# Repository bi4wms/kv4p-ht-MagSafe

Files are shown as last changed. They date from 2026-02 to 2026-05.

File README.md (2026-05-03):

# kv4p-ht-MagSafe
MagSafe version for kv4p-ht. Work in progress.

<a href="https://www.buymeacoffee.com/bi4wms" target="_blank">Buy Me a Coffee</a>
---

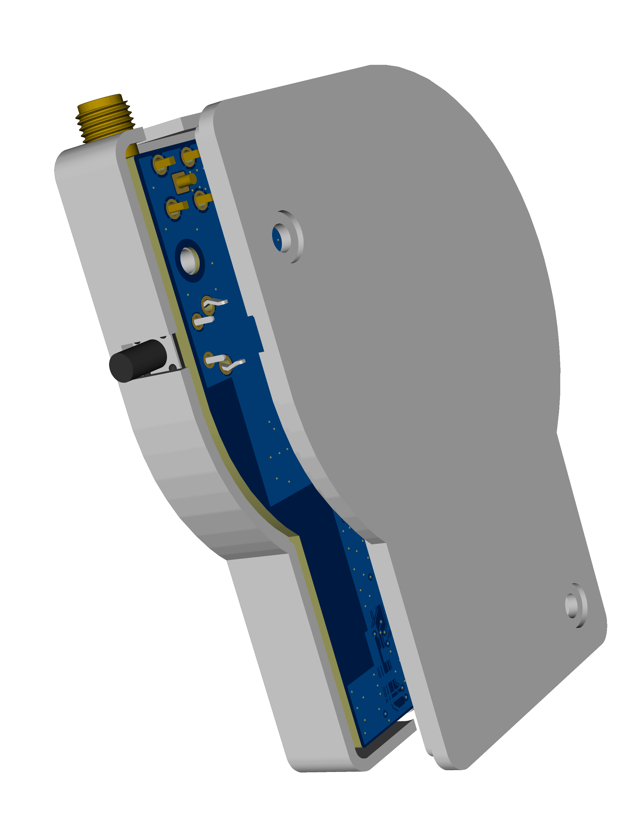
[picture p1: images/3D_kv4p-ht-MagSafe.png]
 

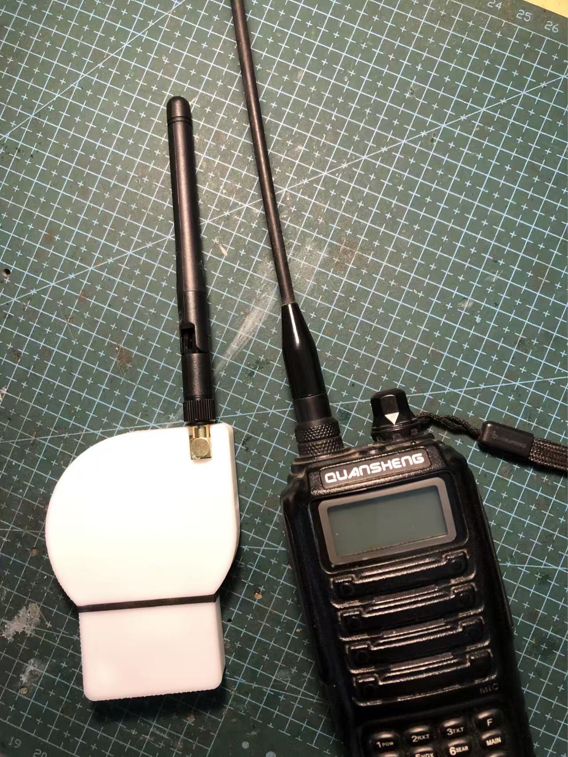
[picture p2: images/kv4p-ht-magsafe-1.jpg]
 

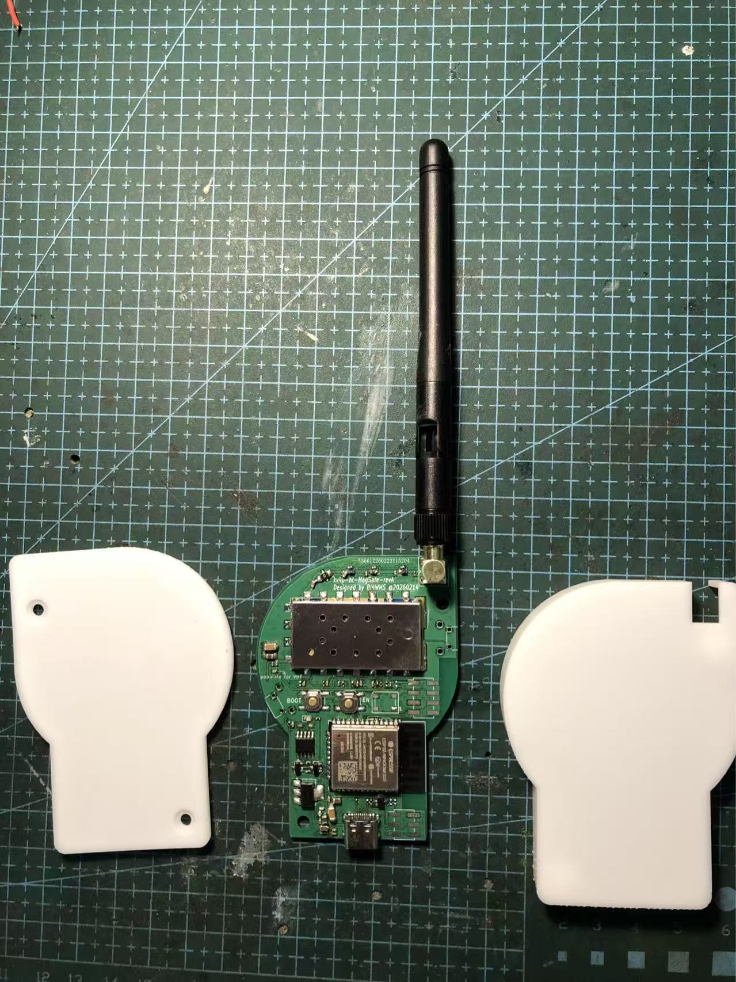
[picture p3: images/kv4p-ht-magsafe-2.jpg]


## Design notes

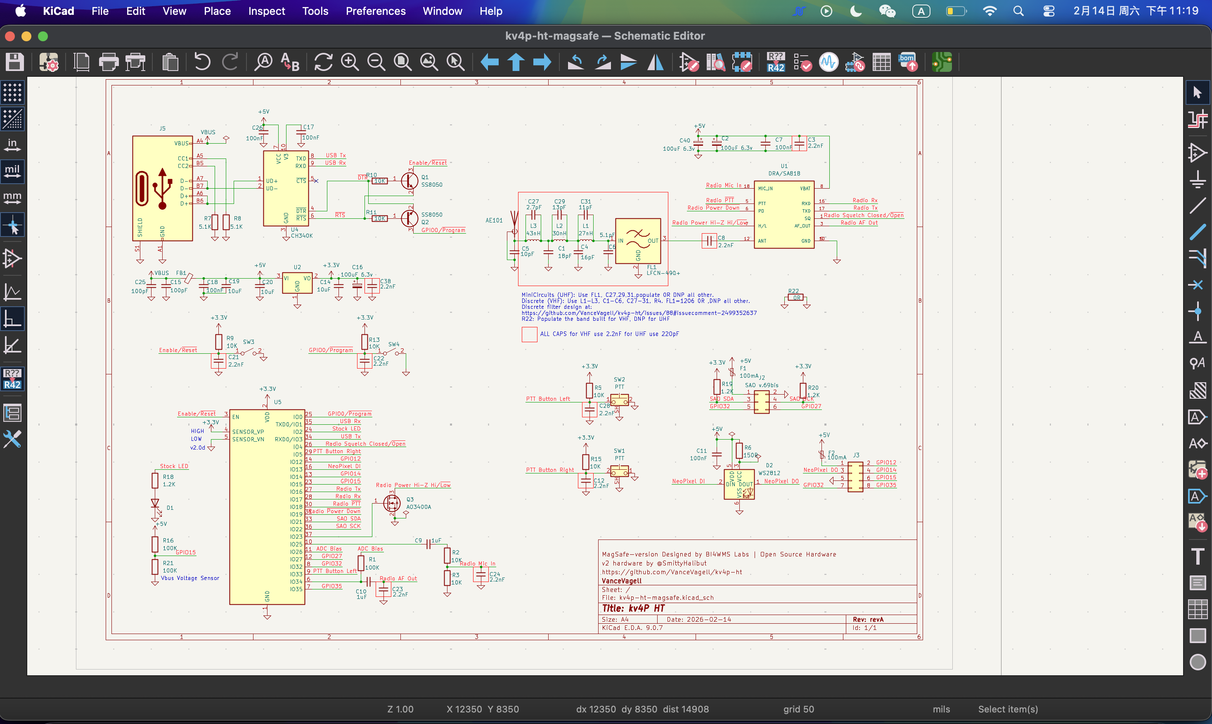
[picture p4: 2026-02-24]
images/schematics.png

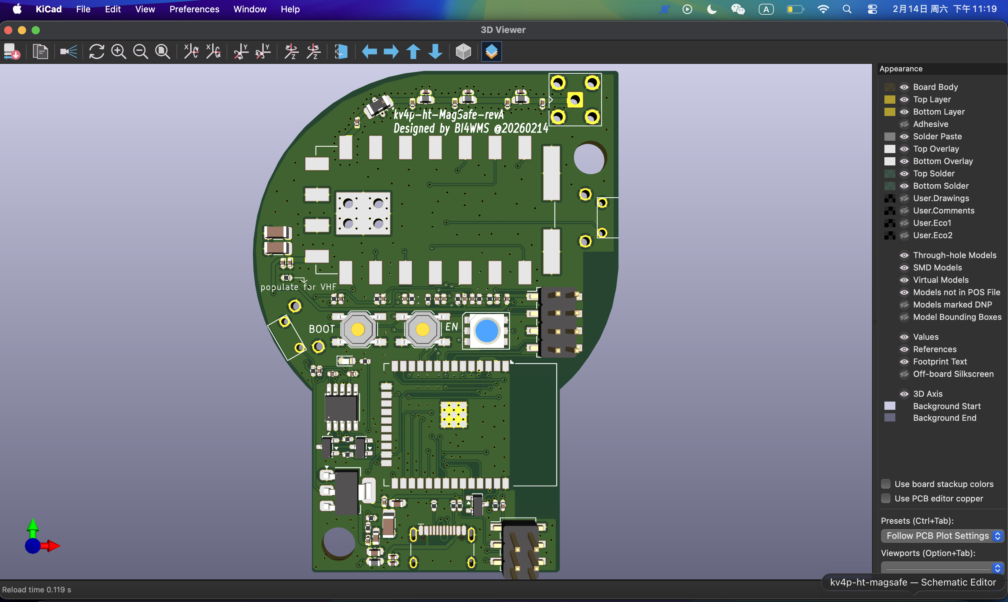
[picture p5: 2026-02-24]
images/PCB.png

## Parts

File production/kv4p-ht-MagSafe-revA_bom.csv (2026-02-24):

Designator | Footprint | Quantity | Value | LCSC Part #
AE101 | SMA_BAT_Wireless_BWSMA-KWE-Z001 | 1 | Antenna_Shield
C1 | 0402 | 1 | 18pF | C1549
C10, C9 | 0402 | 2 | 1uF | C15849
C11, C18, C26, C7 | 0402 | 4 | 100nF | C14663
C12, C21, C22, C23, C24, C28, C3, C38, C8 | 0402 | 9 | 2.2nF | C2168957
C14, C19, C20 | 0603 | 3 | 10uF | C15850
C15, C25 | 0402 | 2 | 100pF | C14858
C16, C2, C40 | 1206 | 3 | 100uF 6.3v | C16133
C17 | 0402 | 1 | 100nF | C15849
C27 | 0402 | 1 | 2.7pF | C1561
C29 | 0402 | 1 | 13pF | C393681
C31 | 0402 | 1 | 11pF | C527000
C4 | 0402 | 1 | 16pF | C77590
C5 | 0402 | 1 | 10pF | C32949
C6 | 0402 | 1 | 5.1pF | C60220
D1 | 0603 | 1 | RED | C2286
D2 | LED_WS2812_PLCC6_5.0x5.0mm_P1.6mm | 1 | WS2812
F1, F2 | 0402 | 2 | 100mA | C369142
FB1 | 0603 | 1 | Ferrite Bead, 1A | C160982
FL1 | Filter_Mini-Circuits_FV1206 | 1 | LFCN-490+ | C3008205
J2 | PinHeader_2x03_P2.54mm_Vertical_SMD | 1 | SAO v.69bis | C192301
J3 | PinHeader_2x04_P2.54mm_Vertical_SMD | 1 | GPIO Header | C192300
J5 | USB_C_Receptacle_HCTL_HC-TYPE-C-16P-01A | 1 | USB-C Socket | C2894897
L1 | 0603 | 1 | 27nH | C1330812
L2 | 0603 | 1 | 30nH | C3221803
L3 | 0603 | 1 | 43nH | C1330253
Q1, Q2 | SOT-23 | 2 | SS8050 | C2150
Q3 | SOT-23 | 1 | AO3400A
R1, R16, R21 | 0402 | 3 | 100K | C25803
R10, R11, R13, R15, R2, R5, R9 | 0402 | 7 | 10K | C25804
R18, R19, R20 | 0402 | 3 | 1.2K | C22765
R22 | 0402 | 1 | 0R | C17888
R3 | 0402 | 1 | 10K | C22765
R6 | 0402 | 1 | 150R | C22765
R7, R8 | 0402 | 2 | 5.1K | C26000
SW1, SW2 | SW-Push-SPST-Horizontal-C782857 | 2 | PTT | C455252
SW3 | SW_SPST_TL3342 | 1 | Reset | C318884
SW4 | SW_SPST_TL3342 | 1 | Program | C318884
U1 | DORJI_DRA818V | 1 | DRA/SA818
U2 | SOT-223-3_TabPin2 | 1 | AZ1117H-3.3TRG1 | C110474
U4 | SSOP-10-1EP_3.9x4.9mm_P1mm_EP2.1x3.3mm | 1 | CH340K
U5 | ESP32-WROOM-32D | 1 | ESP32-WROOM-32E-N4 | C701341

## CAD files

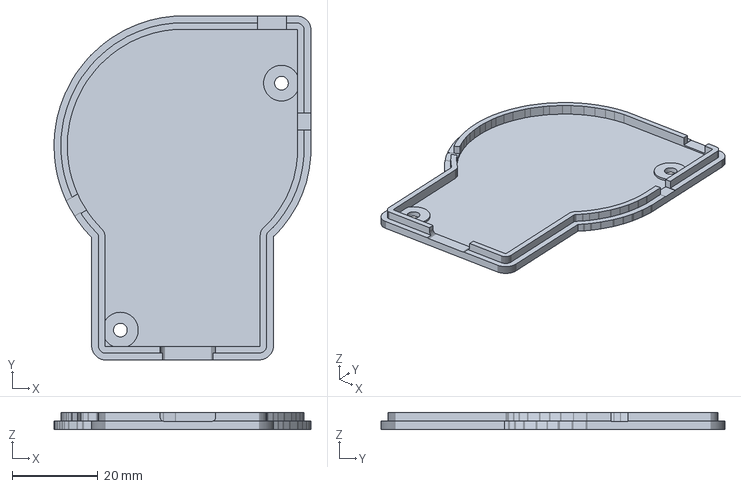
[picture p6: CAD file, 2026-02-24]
3Dfiles/STEP/3DShell_3DShell_kv4p-ht-MagSafe-revA_B.step
60.0 x 80.3 x 4.00 mm

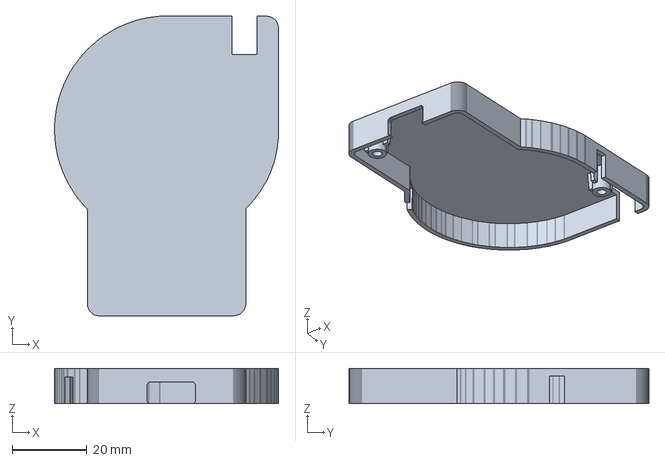
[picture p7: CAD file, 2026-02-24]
3Dfiles/STEP/3DShell_3DShell_kv4p-ht-MagSafe-revA_T.step
60.0 x 80.3 x 9.50 mm

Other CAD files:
3Dfiles/STL/3DShell_3DShell_kv4p-ht-MagSafe-revA_B.stl
3Dfiles/STL/3DShell_3DShell_kv4p-ht-MagSafe-revA_T.stl

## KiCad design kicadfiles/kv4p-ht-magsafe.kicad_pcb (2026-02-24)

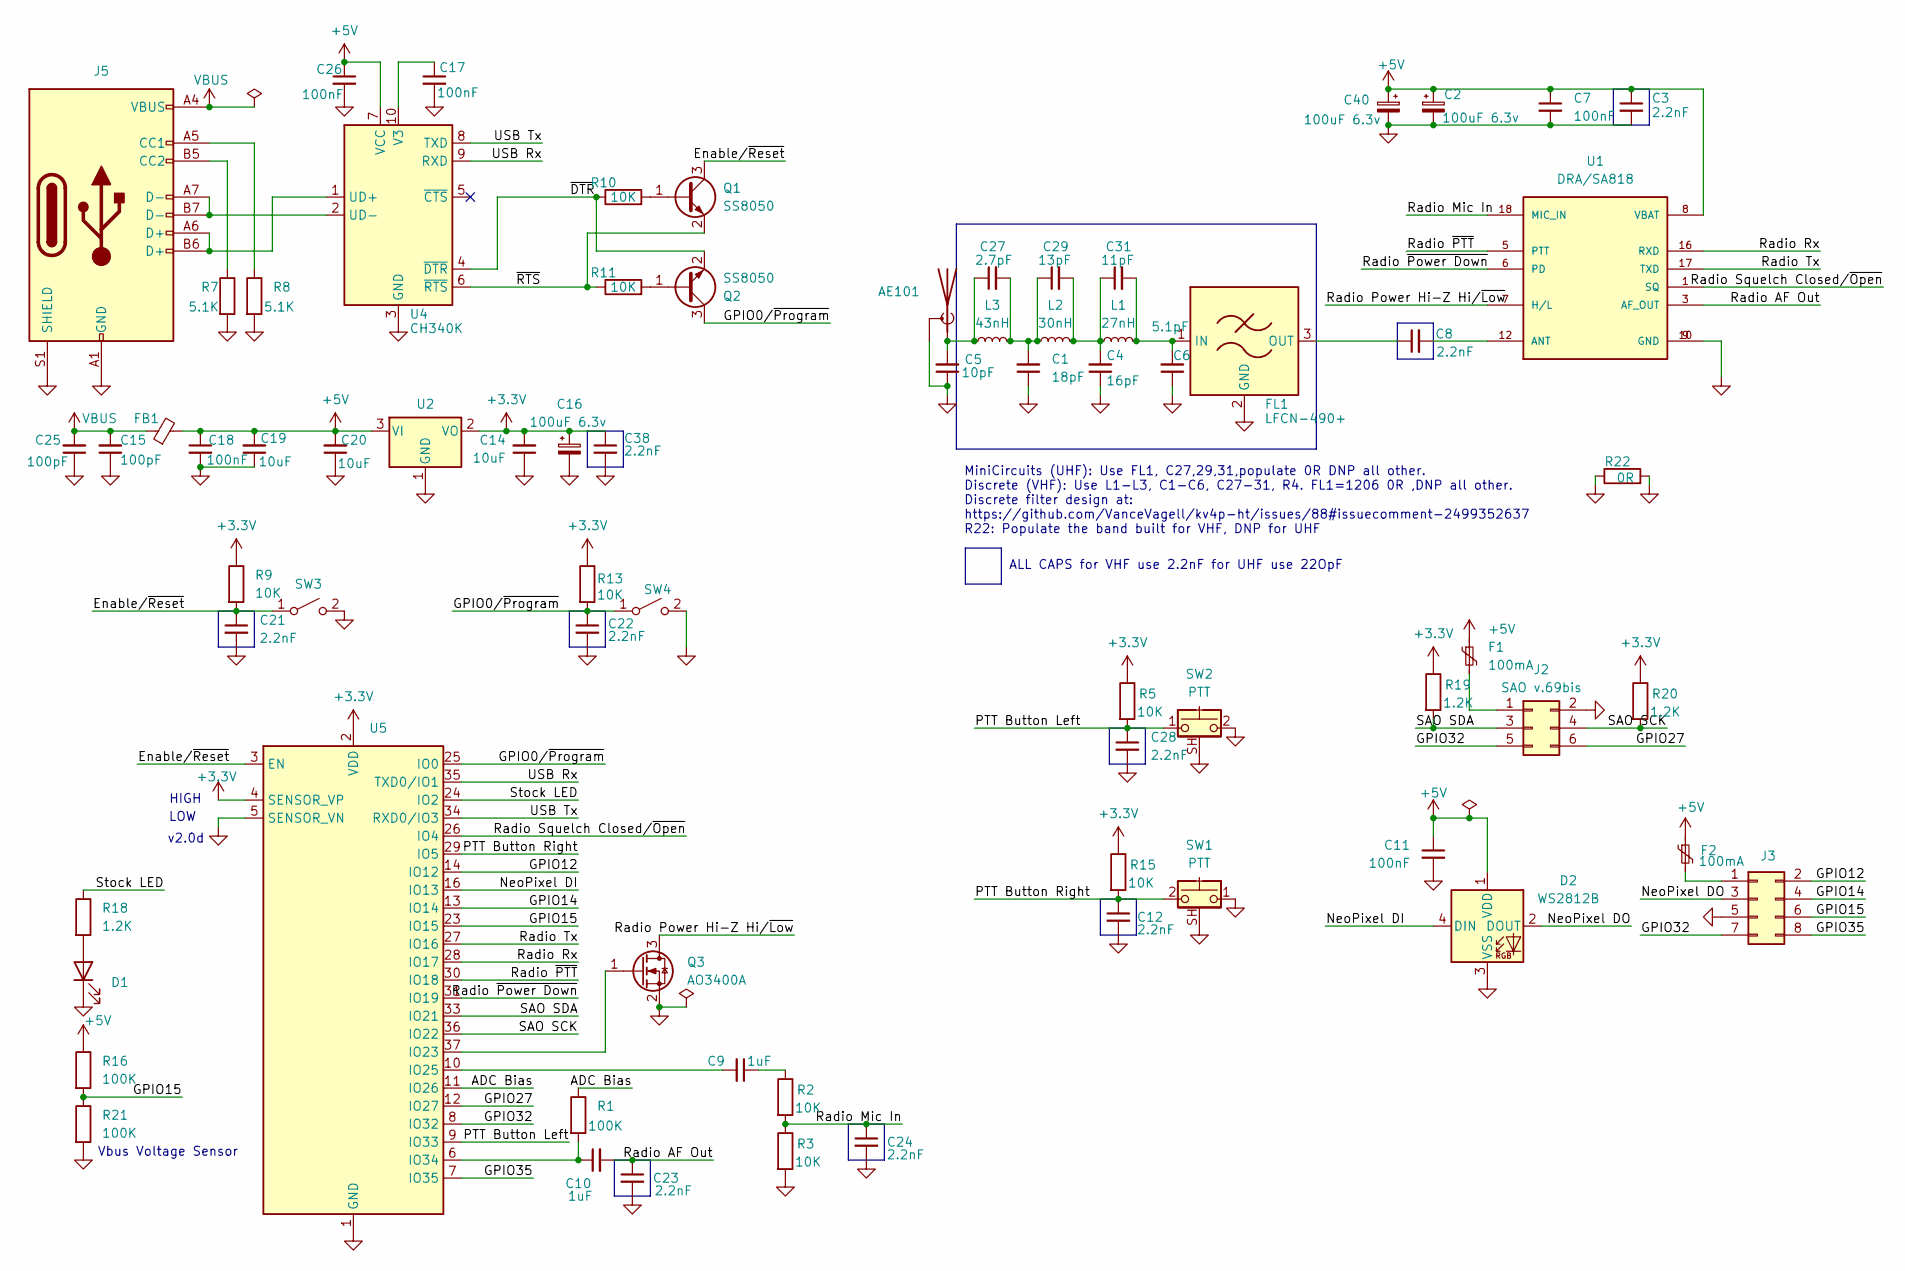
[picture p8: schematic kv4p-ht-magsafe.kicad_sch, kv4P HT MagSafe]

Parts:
AE101: Antenna_Shield; SMA_BAT_Wireless_BWSMA-KWE-Z001
C1: 18pF; C_0402_1005Metric; Part Number Ya basic.; LCSC C1549
C2, C16, C40: 100uF 6.3v; C_1206_3216Metric; LCSC C16133
C3, C8, C12, C21, C22, C23, C24, C28, C38: 2.2nF; C_0402_1005Metric; Part Number GCM1885C1H222FA16D; LCSC C2168957
C4: 16pF; C_0402_1005Metric; Part Number CC0402JRNPO9BN160; LCSC C77590
C5: 10pF; C_0402_1005Metric; Part Number Ya so basic.; LCSC C32949
C6: 5.1pF; C_0402_1005Metric; LCSC C60220
C7, C11, C18, C26: 100nF; C_0402_1005Metric; LCSC C14663
C9, C10: 1uF; C_0402_1005Metric; LCSC C15849
C14, C19, C20: 10uF; C_0603_1608Metric; LCSC C15850
C15, C25: 100pF; C_0402_1005Metric; LCSC C14858
C17: 100nF; C_0402_1005Metric; LCSC C15849
C27: 2.7pF; C_0402_1005Metric; LCSC C1561
C29: 13pF; C_0402_1005Metric; LCSC C393681
C31: 11pF; C_0402_1005Metric; LCSC C527000
D1: RED; LED_0603_1608Metric
D2: WS2812B; LED_WS2812B_PLCC4_5.0x5.0mm_P3.2mm
F1, F2: 100mA; C_0402_1005Metric; LCSC C369142
FB1: Ferrite Bead, 1A; L_0603_1608Metric; Part Number BLM18KG102SN1D; LCSC C160982
FL1: LFCN-490+; Filter_Mini-Circuits_FV1206; LCSC C3008205
J2: SAO v.69bis; PinHeader_2x03_P2.54mm_Vertical_SMD; LCSC C192301
J3: GPIO Header; PinHeader_2x04_P2.54mm_Vertical_SMD; LCSC C192300
J5: USB-C Socket; USB_C_Receptacle_HCTL_HC-TYPE-C-16P-01A; LCSC C2894897
L1: 27nH; L_0603_1608Metric; Part Number LQW2BAN27NJ00L; LCSC C1330812
L2: 30nH; L_0603_1608Metric; Part Number LQW2BAN30NG00L; LCSC C3221803
L3: 43nH; L_0603_1608Metric; Part Number LQW2BAN43NG00L; LCSC C1330253
Q1, Q2: SS8050; SOT-23
Q3: AO3400A; SOT-23
R1, R16, R21: 100K; R_0402_1005Metric
R2, R3, R5, R9, R10, R11, R13, R15: 10K; R_0402_1005Metric
R7, R8: 5.1K; R_0402_1005Metric
R18, R19, R20: 1.2K; R_0402_1005Metric
R22: 0R; R_0402_1005Metric
SW1, SW2: PTT; SW-Push-SPST-Horizontal-C782857; LCSC C455252
SW3: Reset; SW_SPST_TL3342; LCSC C318884
SW4: Program; SW_SPST_TL3342; LCSC C318884
U1: DRA/SA818; DORJI_DRA818V; PART_REV 1.23
U2: AZ1117H-3.3TRG1; SOT-223-3_TabPin2; LCSC C110474
U4: CH340K; SSOP-10-1EP_3.9x4.9mm_P1mm_EP2.1x3.3mm
U5: ESP32-WROOM-32E-N4; ESP32-WROOM-32D; LCSC C701341

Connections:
+3.3V: C14.2, C16.1, C38.1, R5.1, R9.1, R13.1, R15.1, R19.1, R20.1, U2.2 (VO), U5.2 (VDD), U5.4 (SENSOR_VP)
+5V: C2.1, C3.1, C7.1, C11.1, C18.1, C19.2, C20.2, C26.1, C40.1, D2.1 (VDD), F1.1, F2.1, FB1.2, R16.1, U1.8 (VBAT), U2.3 (VI), U4.7 (VCC)
/ADC Bias: R1.1, U5.11 (IO26)
/Enable/~Reset: C21.1, Q1.3 (C), R9.2, SW3.1 (A), U5.3 (EN)
/GPIO0/~Program: C22.1, Q2.3 (C), R13.2, SW4.1 (A), U5.25 (IO0)
/GPIO12: J3.2, U5.14 (IO12)
/GPIO14: J3.4, U5.13 (IO14)
/GPIO15: J3.6, R16.2, R21.1, U5.23 (IO15)
/GPIO27: J2.6, U5.12 (IO27)
/GPIO32: J2.5, J3.7, U5.8 (IO32)
/GPIO35: J3.8, U5.7 (IO35)
/NeoPixel DI: D2.4 (DIN), U5.16 (IO13)
/NeoPixel DO: D2.2 (DOUT), J3.3
/PTT Button Left: C28.1, R5.2, SW2.1, U5.9 (IO33)
/PTT Button Right: C12.1, R15.2, SW1.2, U5.29 (IO5)
/Radio AF Out: C10.2, C23.1, U1.3 (AF_OUT)
/Radio Mic In: C24.1, R2.2, R3.1, U1.18 (MIC_IN)
/Radio Power Hi-Z Hi/~Low: Q3.3 (D), U1.7 (H/L)
/Radio Rx: U1.16 (RXD), U5.28 (IO17)
/Radio Squelch Closed/~Open: U1.1 (SQ), U5.26 (IO4)
/Radio Tx: U1.17 (TXD), U5.27 (IO16)
/Radio ~PTT: U1.5 (PTT), U5.30 (IO18)
/Radio ~Power Down: U1.6 (PD), U5.31 (IO19)
/SAO SCK: J2.4, R20.2, U5.36 (IO22)
/SAO SDA: J2.3, R19.2, U5.33 (IO21)
/Stock LED: R18.1, U5.24 (IO2)
/USB Rx: U4.9 (RXD), U5.35 (TXD0/IO1)
/USB Tx: U4.8 (TXD), U5.34 (RXD0/IO3)
/~DTR: Q2.2 (E), R10.1, U4.4 (~DTR)
/~RTS: Q1.2 (E), R11.1, U4.6 (~RTS)
GND: AE101.2 (Shield), C1.1, C2.2, C3.2, C4.1, C5.1, C6.1, C7.2, C11.2, C12.2, C14.1, C15.1, C16.2, C17.2, C18.2, C19.1, C20.1, C21.2, C22.2, C23.2, C24.2, C25.1, C26.2, C28.2, C38.2, C40.2, D1.1 (K), D2.3 (VSS), FL1.2 (GND), FL1.4 (GND), J2.2, J3.5, J5.A1 (GND), J5.A12 (GND), J5.B1 (GND), J5.B12 (GND), J5.S1 (SHIELD), Q3.2 (S), R3.2, R7.2, R8.2, R21.2, R22.1, R22.2, SW1.1, SW1.SH (B), SW2.2, SW2.SH (B), SW3.2 (B), SW4.2 (B), U1.9 (GND), U1.10 (GND), U2.1 (GND), U4.3 (GND), U4.11 (GND), U5.1 (GND), U5.5 (SENSOR_VN), U5.15 (GND), U5.38 (GND), U5.39 (GND)
unnamed: AE101.1 (A), C5.2, C27.1, L3.1
unnamed: C1.2, C27.2, C29.1, L2.1, L3.2
unnamed: C9.1, R2.1
unnamed: C4.2, C29.2, C31.1, L1.1, L2.2
unnamed: D1.2 (A), R18.2
unnamed: C6.2, C31.2, FL1.1 (IN), L1.2
unnamed: C8.1, FL1.3 (OUT)
unnamed: F1.2, J2.1
unnamed: F2.2, J3.1
unnamed: J5.A5 (CC1), R8.1
unnamed: J5.B5 (CC2), R7.1
unnamed: Q1.1 (B), R10.2
unnamed: Q2.1 (B), R11.2
unnamed: Q3.1 (G), U5.37 (IO23)
unnamed: C8.2, U1.12 (ANT)
unnamed: J5.A6 (D+), J5.B6 (D+), U4.1 (UD+)
unnamed: J5.A7 (D-), J5.B7 (D-), U4.2 (UD-)
unnamed: C17.1, U4.10 (V3)
unnamed: C9.2, U5.10 (IO25)
unnamed: C10.1, R1.2, U5.6 (IO34)
VBUS: C15.2, C25.2, FB1.1, J5.A4 (VBUS), J5.A9 (VBUS), J5.B4 (VBUS), J5.B9 (VBUS)

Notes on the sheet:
MiniCircuits (UHF): Use FL1, C27,29,31,populate 0R DNP all other. Discrete (VHF): Use L1-L3, C1-C6, C27-31, R4. FL1=1206 0R ,DNP all other. Discrete filter design at: https://github.com/VanceVagell/kv4p-ht/issues/88#issuecomment-2499352637 R22: Populate the band built for VHF, DNP for UHF
ALL CAPS for VHF use 2.2nF for UHF use 22OpF
v2.0d
LOW
HIGH
Vbus Voltage Sensor

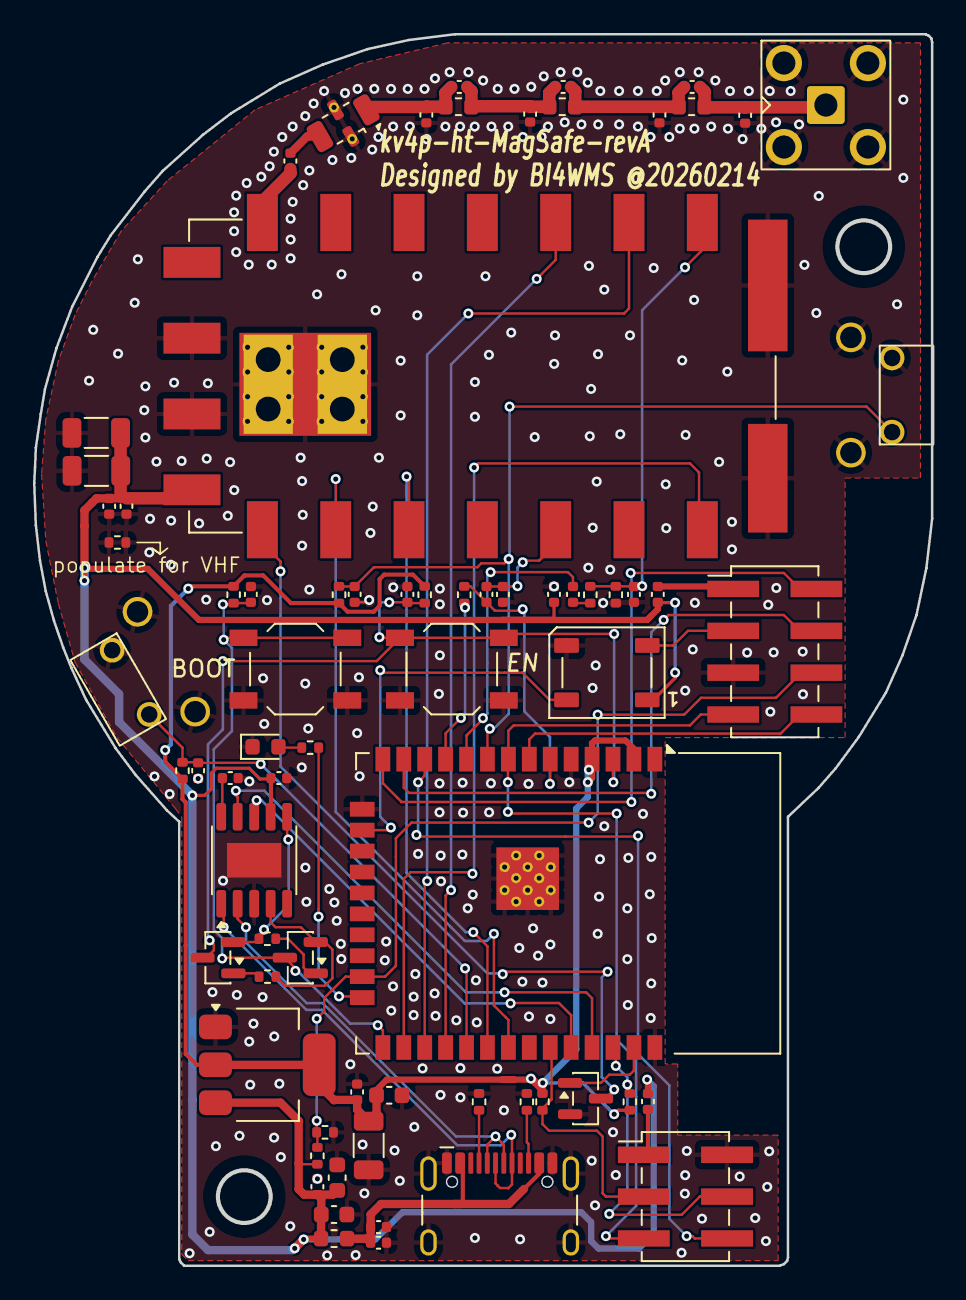
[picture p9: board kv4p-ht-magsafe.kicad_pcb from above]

Board: 2 copper layers, 54.5 x 74.8 mm, 72 parts (0 on the bottom side), 52 nets.

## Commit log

2026-02-24 Add Ko-fi button and update image in README
2026-05-03 Update README with 3D case images
    Added images to README for visual representation.
